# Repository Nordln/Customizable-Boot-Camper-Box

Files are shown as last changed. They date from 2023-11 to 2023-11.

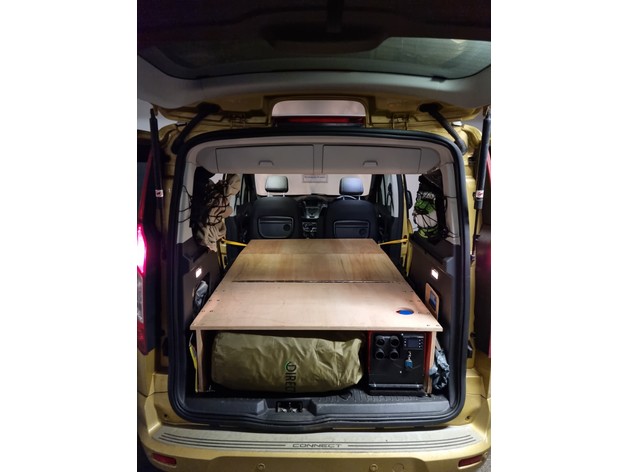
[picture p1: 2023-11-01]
20211127_100647_Medium.jpg

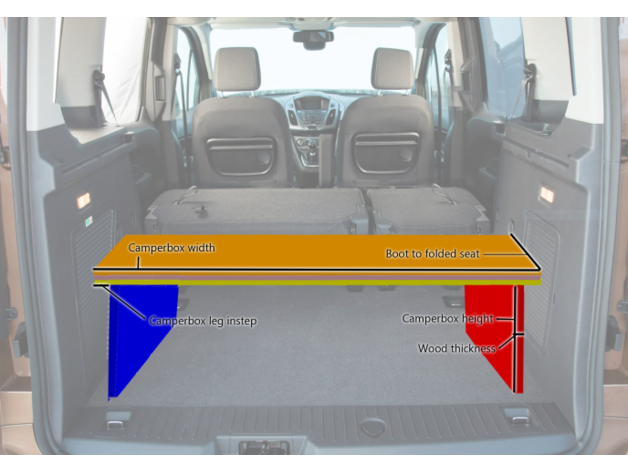
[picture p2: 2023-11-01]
featured_preview_Camperbox_folded_dims_sm.png

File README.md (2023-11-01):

# Customizable-Boot-Camper-Box
Customizable Boot Camper Box

A customisable boot camperbox, tested and successfully used during two driving vacations to the Outer Hebrides, Scotland. The model can be size-adjusted and toggled between folded and unfolded.

Designed for the Ford Tourneo Connect 2014, with the rear seats folded down (not rocked forward in the footwell) and the front seats pushed all the way forward. The design can be customized using OpenSCAD or the Thingiverse Customizer to fit similar vehicles. 

The legs are attached using two L-angle aluminium bar secured with pop rivets. This has proven to be very durable. Standard piano hinges were attached to the edges of the moving surfaces to allow folding.

To fold out, the rear seats are locked forward with the first unfolded surface laid over them.  A towing strap modified with loops at either-end is fitted as a bridge between the chassis catch bolts on each of the sliding doors. This is used as support for the second unfolded surface. Both doors still securely lock whilst the strap is attached.

The wood used was sourced from B&Q (a UK hardware retailer) and cut at the store using the free wood cutting service. The model can be toggled to show the primitive objects that make the model. In this mode, the parts are also visually mapped against a typical 25mm x 1220mm x 2450mm plywood board. This is provided as an easy reference for the in-store saw operator.  The number of cuts fits inside the maximum number of cuts the store staff permit customers to have (although this varies from store to store).

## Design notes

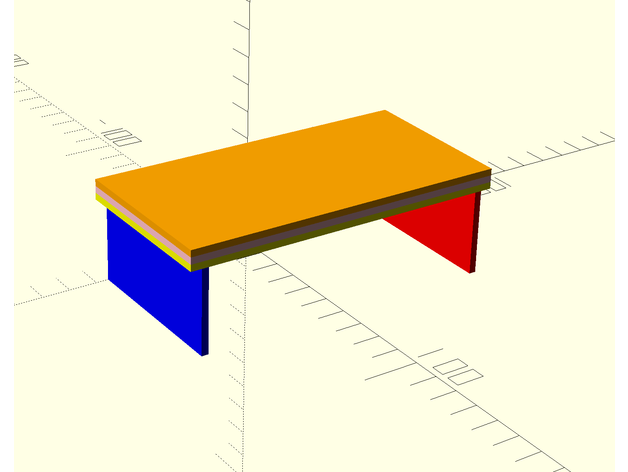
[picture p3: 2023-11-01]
featured_preview_CamperboxV3_folded.png

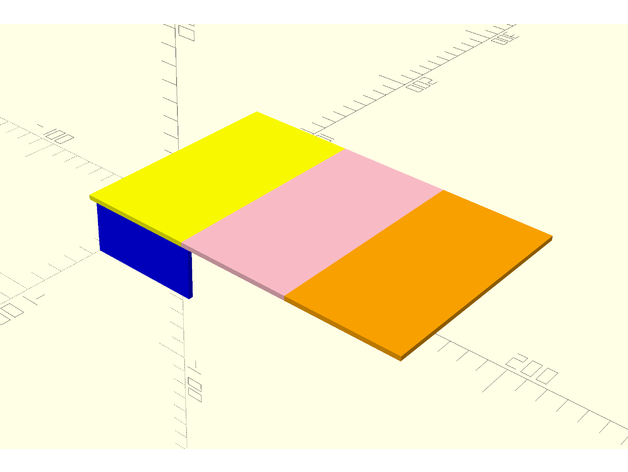
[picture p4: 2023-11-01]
featured_preview_CamperboxV3_unfolded.png

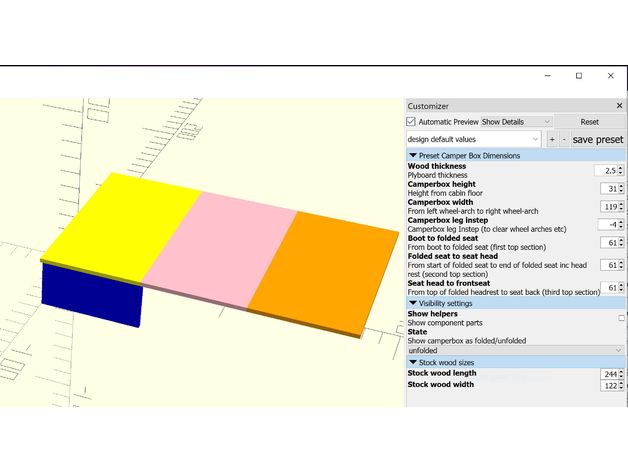
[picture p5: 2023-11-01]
featured_preview_Varibles.jpg

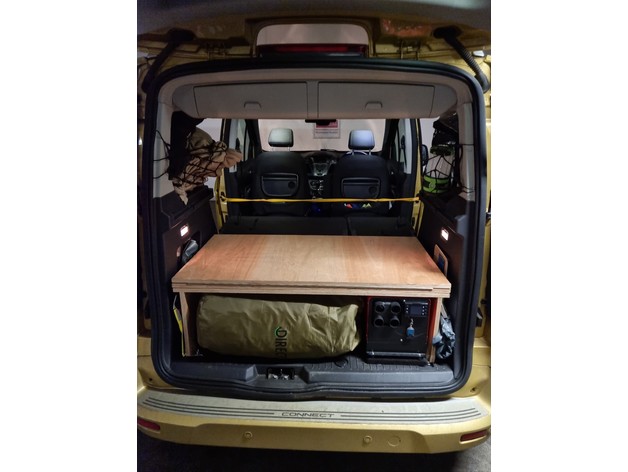
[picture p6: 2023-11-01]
20211127_100553_Medium.jpg

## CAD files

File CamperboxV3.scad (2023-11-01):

/* [Preset Camper Box Dimensions] */

// Plyboard thickness
Wood_thickness = 2.5;

// Height from cabin floor
Camperbox_height = 31;

// From left wheel-arch to right wheel-arch
Camperbox_width = 119;

// Camperbox leg Instep (to clear wheel arches etc)
Camperbox_leg_instep = -4; 

// From boot to folded seat (first top section)
Boot_to_folded_seat = 61;

// From start of folded seat to end of folded seat inc head rest (second top section)
Folded_seat_to_seat_head = 61; 

// From top of folded headrest to seat back (third top section)
Seat_head_to_frontseat = 61; 


/* [Visibility settings] */

// Show component parts
Show_helpers = 0; // [0:"Box", 1:"Cut guide"]

// Show camperbox as folded/unfolded
State = "unfolded"; // [folded, unfolded]
Wood_thicknessop2_a = (State == "unfolded") ? 0 : 180; // angle of top2 (180 = folded, 0 = unfolded)
Wood_thicknessop3_a = (State == "unfolded") ? 0 : -180; // angle of top3 (-180 = folded 0 = unfolded)

/* [Stock wood sizes] */
Stock_wood_length = 244; // long-side length
Stock_wood_thickness = Wood_thickness; // thickness
Stock_wood_width = 122; // short-side width

//module __Customizer_Limit__ () {}
/* [Hidden] */

// Global rescaler (X*1)
rescaler = 1; 

// Min. facet render level 
$fs = 0.1;  // Don't generate smaller facets than 0.1

// Min angles render level (deg)
$fa = 5;    // Don't generate larger angles than 5 degrees

// Horiz. spacing between debug parts
debug_spacing_y = 15;

// Vert. spacing between debug parts
    
debug_spacing_z =0; 


/* [top1 dimensions] */

// Thickness of box
top1_x = Boot_to_folded_seat;
// Width of box
top1_y = Wood_thickness;
// Height of box
top1_z = Camperbox_width; 


/* [top2 dimensions] */

// Thickness of box
top2_x = Folded_seat_to_seat_head;
// Width of box 
top2_y = Wood_thickness;
// Height of box
top2_z = Camperbox_width; 


/* [top3 dimensions] */

// Thickness of box
top3_x = Seat_head_to_frontseat;
// Width of box
top3_y = Wood_thickness;
// Height of box
top3_z = Camperbox_width; 


/* [lside dimensions] */

// Thickness of box
lside_x = Boot_to_folded_seat;
// Width of box
lside_y = Wood_thickness;
// Height of box
lside_z = Camperbox_height; 


/* [rside dimensions] */

// Thickness of box
rside_x = Boot_to_folded_seat;
// Width of box
rside_y = Wood_thickness;
// Height of box
rside_z = Camperbox_height; 

// Main geometry
if (Show_helpers == 0) camperbox();


// Core geometric primitives

module lside(arg = "") {
    color("blue") cube([lside_x,lside_y,lside_z], center=true);
    if (arg == "show_dims") printdims(lside_x,lside_y,lside_z);
}

module rside(arg = "") {
    color("red") cube([rside_x,rside_y,rside_z], center=true);
    if (arg == "show_dims") printdims(rside_x,rside_y,rside_z);
}

module top1(arg = "") {
    color("yellow") cube([top1_x,top1_y,top1_z], center=true);
    if (arg == "show_dims") printdims(top1_x,top1_y,top1_z);
}

module top2(arg = "") {
        color("pink") cube([top2_x,top2_y,top2_z], center=true);
        if (arg == "show_dims") printdims(top2_x,top2_y,top2_z);
}

module top3(arg = "") {
    color("orange") cube([top3_x,top3_y,top3_z], center=true);
    if (arg == "show_dims") printdims(top3_x,top3_y,top3_z);
}


// Intermediate components

module top2_3() {
    rotate([0,0,Wood_thicknessop2_a]) 
        union() {
            translate([0+top2_x/2,0-Wood_thickness/2,0]) top2();
            translate([Folded_seat_to_seat_head,0-Wood_thickness,0]) rotate([0,0,Wood_thicknessop3_a]) translate([0+top3_x/2,Wood_thickness/2,0]) top3();
        }
}

module camperbox() {
    translate ([0+Boot_to_folded_seat/2,0-Camperbox_width/2-Camperbox_leg_instep+Wood_thickness/2,0+Camperbox_height/2]) rotate([0,0,0]) lside();
    translate ([0+Boot_to_folded_seat/2,Camperbox_width/2+Camperbox_leg_instep-Wood_thickness/2,0+Camperbox_height/2]) rotate([0,0,0]) rside();
    translate ([0+Boot_to_folded_seat/2,0,Camperbox_height/2 + top1_y/2 + Camperbox_height/2]) rotate([90,0,0]) top1();
    translate ([0+Boot_to_folded_seat,0,Camperbox_height/2 + top2_y/2 + Camperbox_height/2 + Wood_thickness/2]) rotate([90,0,0]) top2_3(); 
}

// debug display 
//***************

// Helpers
if (Show_helpers == 1) helpers();
    
module printdims (x, y, z) {
    rotate([90,0,0]) translate([0-x/2 + 1,0+z/2 - 1,Wood_thickness/2]) color("black") text(str("X: ", x, ", ", "Y: ", y, ", ", "Z: ", z, ", "), size = 4, valign = "top");
}

module helpers() {
    
    // primitives
/*
    translate([0 + lside_x/2, 0 + debug_spacing_y*2 - lside_y/2, debug_spacing_z  * -1]) lside("show_dims");
    translate([0 + rside_x/2, 0 + debug_spacing_y*4 - rside_y/2, debug_spacing_z * -1]) rside("show_dims");
    translate([0 + top1_x/2, 0 + debug_spacing_y*6 - top1_y/2, debug_spacing_z * -1]) top1("show_dims");
    translate([0 + top2_x/2, 0 + debug_spacing_y*8 - top2_y/2, debug_spacing_z * -1]) top2("show_dims");
    translate([0+ top3_x/2, 0 + debug_spacing_y*10 - top2_y/2, debug_spacing_z * -1]) top3("show_dims");
    
 */
    
    translate([0,0, debug_spacing_z * -3])  cube([Stock_wood_length,Stock_wood_thickness,Stock_wood_width]);  // the shop-brought wood for cutting
    translate([0 + top1_x/2, 0 - top1_y/2, (debug_spacing_z * -3) + top1_z/2]) top1("show_dims");
    translate([0 + top2_x/2 + top1_x, 0 - top2_y/2, (debug_spacing_z * -3) + top2_z/2]) top2("show_dims");
    translate([0 + top3_x/2 + top1_x + top2_x, 0 - top2_y/2, (debug_spacing_z * -3) + top3_z/2]) top3("show_dims");
    translate([0 + lside_z/2 + top1_x + top2_x + top3_x, 0 - lside_y/2, (debug_spacing_z  * -3) + lside_x/2]) rotate([0,90,0]) lside("show_dims");
    translate([0 + rside_z/2 + top1_x + top2_x + top3_x, 0 - rside_y/2, (debug_spacing_z  * -3) + rside_x/2 + rside_x]) rotate([0,90,0]) rside("show_dims");
    translate([0 + lside_z/2 + top1_x + top2_x + top3_x + lside_z, 0 - lside_y/2, (debug_spacing_z  * -3) + lside_x/2]) rotate([0,90,0]) lside("show_dims");
    translate([0 + rside_z/2 + top1_x + top2_x + top3_x + lside_z, 0 - rside_y/2, (debug_spacing_z  * -3) + rside_x/2 + rside_x]) rotate([0,90,0]) rside("show_dims");

}


echo(version=version());
// Written by Ed Watson <mail@edwardwatson.co.uk>
//
// To the extent possible under law, the author(s) have dedicated all
// copyright and related and neighboring rights to this software to the
// public domain worldwide. This software is distributed without any
// warranty.
//
// You should have received a copy of the CC0 Public Domain
// Dedication along with this software.
// If not, see <http://creativecommons.org/publicdomain/zero/1.0/>.

              
